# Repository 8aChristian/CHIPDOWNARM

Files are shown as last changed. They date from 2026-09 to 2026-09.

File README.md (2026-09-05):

# CHIPDOWNARM | Sub-GHz LoRaWAN & Industrial Telemetry Node

CHIPDOWNARM is a highly optimized, industrial-grade IoT telemetry edge node designed for mission-critical Sub-GHz LPWAN networks, remote monitoring, and smart agriculture deployments. Built around the high-performance **STMicroelectronics STM32WLE5** (ARM Cortex-M4 with integrated Sub-GHz LoRa/FSK transceiver), it delivers robust long-range communication with an ultra-low power footprint.

The board follows rigorous IPC (IPC-2152, IPC-2221) standards, featuring a wide-input high-efficiency switching power architecture (TPS62840), a highly stable 32MHz TCXO for RF precision, and an optimized 4-layer controlled-impedance stackup for impeccable RF Signal Integrity (SI) and Power Integrity (PI).

---

## 📸 Photorealistic 3D Renders

<p align="center">
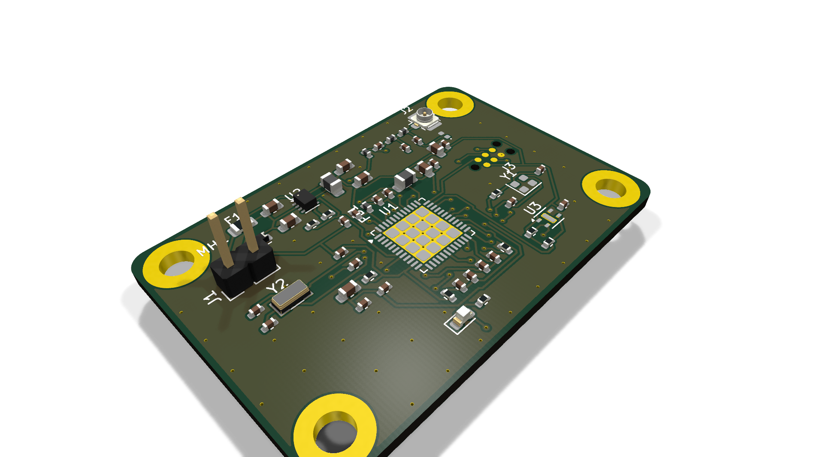
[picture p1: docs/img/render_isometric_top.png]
CHIPDOWNARM 3D Top View
  
</p>

<p align="center">
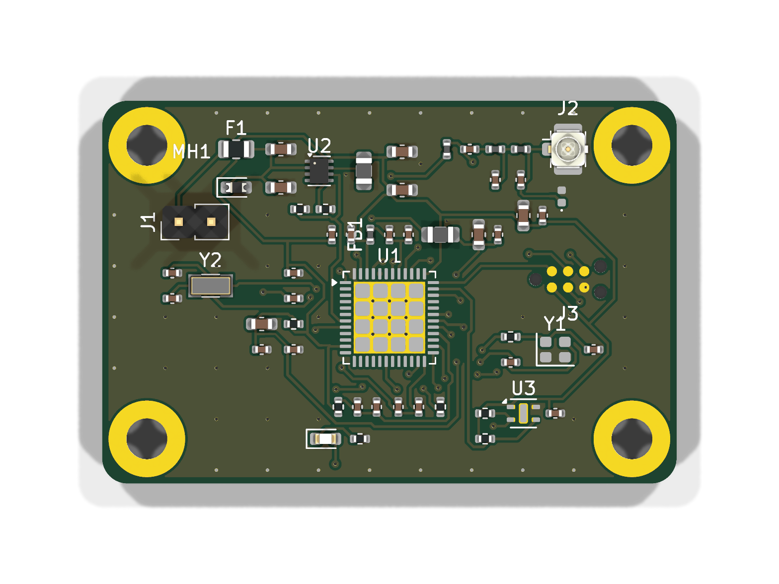
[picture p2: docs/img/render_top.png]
Top Orthographic View
  
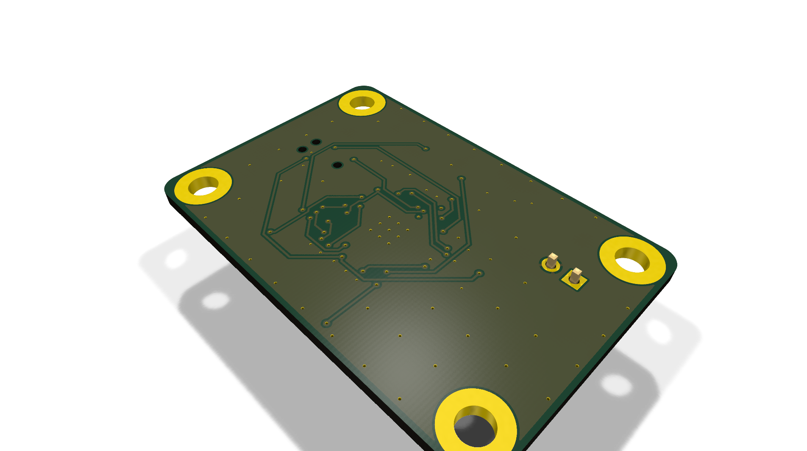
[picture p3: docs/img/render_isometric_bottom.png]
Bottom Isometric View
  
</p>

---

## 🏛️ System Architecture Diagram

```mermaid
flowchart TD
    subgraph PowerDomain["⚡ Power Architecture (1.8V - 6.5V)"]
        VIN["DC Power In (J1) / Li-SOCl2 / Li-Po"] --> F1["Polyfuse PTC (F1)"]
        F1 --> D1["TVS Diode Protection"]
        D1 --> U2["TI TPS62840 Buck (60nA Iq)"]
        U2 --> L1["1.5µH Shielded Inductor"]
        L1 --> VCC3["+3V0 System Rail"]
        VCC3 --> FB1["Ferrite Bead (FB1)"]
        FB1 --> VDDA["Filtered Analog Power (VDDA)"]
    end

    subgraph CoreDomain["🧠 Compute and RF Engine"]
        U1["STM32WLE5CCU6 (ARM Cortex-M4 @ 48MHz)"]
        Y1["32.000 MHz TCXO (Y1)"] -->|"RF Master Clock"| U1
        Y2["32.768 kHz RTC Crystal (Y2)"] -->|"Low Power RTC"| U1
        VCC3 --> U1
        VDDA --> U1
    end

    subgraph RFDomain["📡 Sub-GHz RF Frontend (150-960 MHz)"]
        U1 -->|"RF_PA_OUT"| RFFilt["LC Harmonics Filter & Matching Network"]
        RFFilt -->|"50Ω Coplanar Microstrip"| J2["SMA Edge-Mount Connector (J2)"]
    end

    subgraph SensorDomain["🌡️ Telemetry and Sensing"]
        U3["Sensirion SHTC3 (I2C)"] -->|"I2C1_SCL / I2C1_SDA"| U1
        VCC3 --> U3
    end

    subgraph DebugDomain["🔧 Diagnostics and Programming"]
        J3["Tag-Connect TC2030-IDC-NL"] -->|"SWDIO, SWCLK, NRST, SWO"| U1
    end

    classDef pwr fill:#f97316,stroke:#c2410c,stroke-width:2px,color:#fff;
    classDef core fill:#2563eb,stroke:#1d4ed8,stroke-width:2px,color:#fff;
    classDef rf fill:#16a34a,stroke:#15803d,stroke-width:2px,color:#fff;
    classDef sns fill:#9333ea,stroke:#7e22ce,stroke-width:2px,color:#fff;
    classDef dbg fill:#475569,stroke:#334155,stroke-width:2px,color:#fff;

    class PowerDomain,VIN,F1,D1,U2,L1,VCC3,FB1,VDDA pwr;
    class CoreDomain,U1,Y1,Y2 core;
    class RFDomain,RFFilt,J2 rf;
    class SensorDomain,U3 sns;
    class DebugDomain,J3 dbg;
```

---

## ⚡ Power Tree & Energy Profile

```mermaid
flowchart LR
    BATT["Battery / External Input<br/><b>1.8V - 6.5V</b>"] -->|F1: PTC Fuse| REG["TPS62840<br/><b>Buck Regulator</b><br/>Iq = 60 nA | Eff = 92%"]
    REG -->|VOUT = 3.0V| RAIL["+3V0 System Rail<br/>(Inner Layer 2 Plane)"]
    
    RAIL -->|"100nF + 4.7µF"| MCU["STM32WLE5 Core<br/>Sleep: 1.1 µA<br/>TX (+22dBm): 118 mA"]
    RAIL -->|"100nF"| SENS["SHTC3 Sensor<br/>Active: 800 µA<br/>Sleep: 0.2 µA"]
    RAIL -->|"100nF + TCXO Reg"| TCXO["32 MHz TCXO<br/>Warmup: 2 ms"]
    RAIL -->|FB1: Ferrite Filter| RF_ANA["RF & VDDA Power<br/>Multi-stage decoupling"]
```

---

## 🔬 PCB Layer Stackup & Controlled Impedance

The PCB is built on an industrial 4-Layer standard stackup (1.6mm nominal thickness, 1 oz / 35µm copper outer and inner layers) to guarantee excellent RF containment.

```text
========================================================================================
Layer 1 (Top / F.Cu): Component SMD Pads, 50Ω RF Coplanar Microstrips, Buck Power Loop
---------------------------------- Dielectric Prepreg (0.21mm, FR-4, Er=4.5) -----------
Layer 2 (Inner 1 / In1.Cu): Solid Continuous Ground Plane (GND) - Zero Slots
---------------------------------- Core Dielectric (1.065mm, FR-4, Er=4.5) -------------
Layer 3 (Inner 2 / In2.Cu): Dedicated +3V0 Power Plane & RF Return Shield
---------------------------------- Dielectric Prepreg (0.21mm, FR-4, Er=4.5) -----------
Layer 4 (Bottom / B.Cu): Digital Control Signals & Secondary Ground Shield
========================================================================================
```

### 🗺️ Individual Layer Vector Views

| Layer | Type | Function & High-Speed Details | Vector Preview |
| :--- | :--- | :--- | :--- |
| **L1 (F.Cu)** | Signal / RF | 50Ω Coplanar RF track, SMPS power loop, MCU breakouts | [View SVG](docs/img/layer_l1_top.svg) |
| **L2 (In1.Cu)** | Solid GND | 100% continuous reference ground, zero ground slots | [View SVG](docs/img/layer_l2_gnd.svg) |
| **L3 (In2.Cu)** | Power | Dedicated +3V0 power plane, ultra-low impedance distribution | [View SVG](docs/img/layer_l3_pwr.svg) |
| **L4 (B.Cu)** | Signal / Shield | I2C routing, debug traces, stitched ground plane | [View SVG](docs/img/layer_l4_bottom.svg) |

---

## ⚡ Technical Specifications

| Parameter | Specification | Engineering Details |
| :--- | :--- | :--- |
| **Input Supply Voltage** | **1.8V − 6.5V DC** | Polyfuse protection (F1) + Battery input conditioning for Li-Po/Li-SOCl2. |
| **Main Step-Down Converter** | **TI TPS62840 (1.8V-6.5V)** | Ultra-low $I_q$ (60 nA) high-efficiency buck regulator with compact shielded inductor. |
| **Main Processing Unit (MCU)** | **STM32WLE5CCU6** | ARM Cortex-M4 @ 48MHz, 256KB Flash, 64KB SRAM, integrated Sub-GHz Radio. |
| **Wireless Connectivity** | **LoRa / (G)FSK / (G)MSK** | Sub-GHz Radio (150 MHz to 960 MHz) compatible with LoRaWAN protocols. |
| **RF Clock Source** | **32.000 MHz TCXO** | High-stability Temperature Compensated Oscillator for precise RF modulation. |
| **Telemetry Sensor** | **Sensirion SHTC3** | Ultra-low power I2C Temperature and Humidity sensor (±2.0% RH, ±0.2°C). |
| **Debug Interface** | **SWD via Tag-Connect** | Zero-cost, zero-profile TC2030-IDC-NL footprint (No Legs) for SWD & SWO. |
| **RF Interface** | **SMA Edge-Mount** | 50Ω impedance-matched Coplanar Waveguide routing to SMA connector. |
| **Design Rule Check (DRC)** | **100% Passed (0 Errors)** | 0 Unrouted airwires, 0 clearance errors, full IPC-2221 compliance. |

---

## 📋 Comprehensive Bill of Materials (BOM)

| Item | Qty | Component / Value | Manufacturer | MPN | Description |
| :--- | :--- | :--- | :--- | :--- | :--- |
| **U1** | 1 | **STM32WLE5CCU6** | STMicroelectronics | STM32WLE5CCU6 | ARM Cortex-M4 Sub-GHz LoRa SoC (UFQFPN-48) |
| **U2** | 1 | **TPS62840DLCR** | Texas Instruments | TPS62840DLCR | Ultra-Low Iq Step-Down Converter |
| **U3** | 1 | **SHTC3** | Sensirion | SHTC3 | I2C Humidity and Temperature Sensor |
| **Y1** | 1 | **NT2016SA-32M** | NDK | NT2016SA-32M | 32.000MHz TCXO (Temperature Compensated) |
| **J1** | 1 | **SMA Edge-Mount** | Amphenol | 132136 | 50Ω SMA RF Connector |
| **J3** | 1 | **TC2030-IDC-NL** | Tag-Connect | TC2030-IDC-NL | 6-pin No-Legs SWD Programming Header |

*(For passive components, resistors, MLCCs, and exact footprints, please see [CHIPDOWNARM_BOM.xml](CHIPDOWNARM_BOM.xml))*

---

## 📁 Repository Structure

```text
CHIPDOWNARM/
├── CHIPDOWNARM.kicad_pcb        # KiCad 8/9 PCB Layout File (4-Layer, 0 DRC Errors)
├── CHIPDOWNARM.kicad_sch        # KiCad Schematic File
├── CHIPDOWNARM.kicad_pro        # KiCad Project Definitions
├── CHIPDOWNARM_Schematic.pdf    # Complete vector schematic PDF
├── CHIPDOWNARM.step             # High-precision 3D mechanical model (STEP AP214)
├── CHIPDOWNARM_BOM.xml          # Sourcing Bill of Materials
├── gerbers/                     # Standard RS-274X Fabrication Gerbers & Excellon Drills
│   ├── CHIPDOWNARM-F_Cu.gtl     # Top Copper Layer
│   ├── CHIPDOWNARM-In1_Cu.g1    # Layer 2 Ground Plane
│   ├── CHIPDOWNARM-In2_Cu.g2    # Layer 3 Power Plane
│   ├── CHIPDOWNARM-B_Cu.gbl     # Bottom Copper Layer
│   ├── CHIPDOWNARM.drl          # NC Drill file
│   └── ...                      # Masks, silkscreens, edge cuts
├── docs/
│   └── img/                     # 3D Photorealistic raytracing renders & SVG layer previews
│       ├── render_isometric_top.png
│       ├── render_isometric_bottom.png
│       ├── render_top.png
│       └── layer_l*.svg
├── .gitignore                   # Clean Git configuration for EDA projects
└── README.md                    # Comprehensive hardware documentation
```

---

## 🚀 How to Build & Open the Project

### Prerequisites
* EDA Suite: **[KiCad 8.0+](https://www.kicad.org/)** (Fully tested on KiCad 8 & 9).

### Opening in KiCad
1. Clone the repository:
   ```bash
   git clone https://github.com/8aChristian/CHIPDOWNARM.git
   cd CHIPDOWNARM
   ```
2. Open `CHIPDOWNARM.kicad_pro` inside KiCad.
3. Open the **Schematic Editor** to review the architecture.
4. Open the **PCB Editor** and hit `B` to recalculate all zone fills and inspect the perfectly clean 4-layer layout.
5. Press `Alt + 3` to open the interactive 3D viewer.

---

## 📜 License & Author

**Author**: Christian Ochoa ([@8aChristian](https://github.com/8aChristian))  
**Status**: Ready for Fabrication (0 Unrouted, 0 DRC Violations)  
**License**: Released under the MIT License.

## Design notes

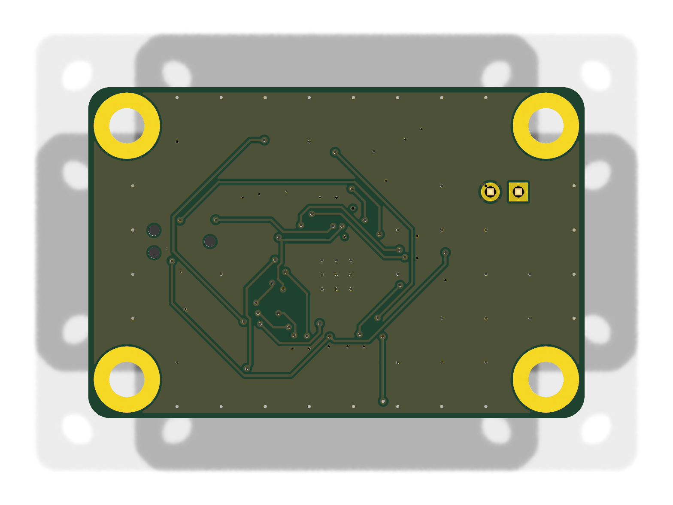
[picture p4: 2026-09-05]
docs/img/render_bottom.png

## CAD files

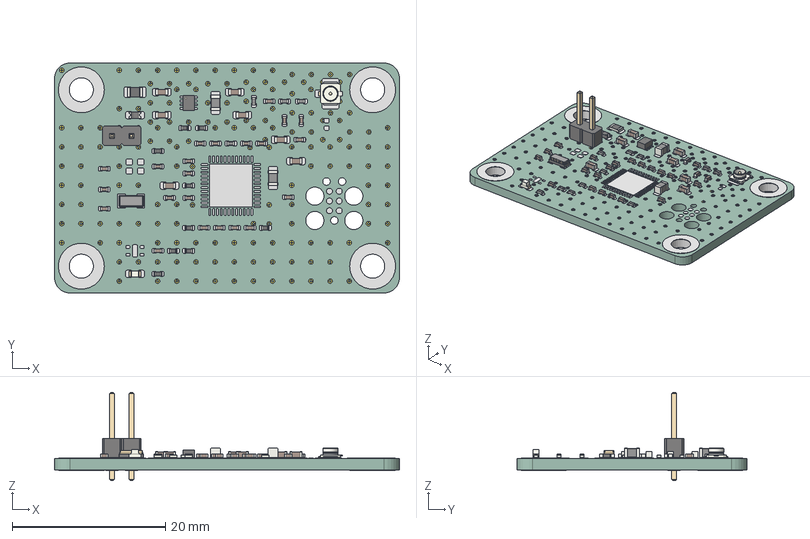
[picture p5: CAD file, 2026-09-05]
CHIPDOWNARM.step
45.0 x 30.0 x 11.5 mm
D_0603_1608Metric
C_0402_1005Metric x 22
Texas_VSON-HR-8_1.5x2mm_P0.5mm
C_0603_1608Metric x 7
L_0402_1005Metric x 4
R_0402_1005Metric x 9
Crystal_SMD_3215-2Pin_3.2x1.5mm
Fuse_0805_2012Metric
L_0805_2012Metric x 2
U.FL_Hirose_U.FL-R-SMT-1_Vertical
LED_0603_1608Metric
PinHeader_1x02_P2.54mm_Vertical
CHIPDOWNARM_copper
CHIPDOWNARM_pad
CHIPDOWNARM_via
CHIPDOWNARM_PCB

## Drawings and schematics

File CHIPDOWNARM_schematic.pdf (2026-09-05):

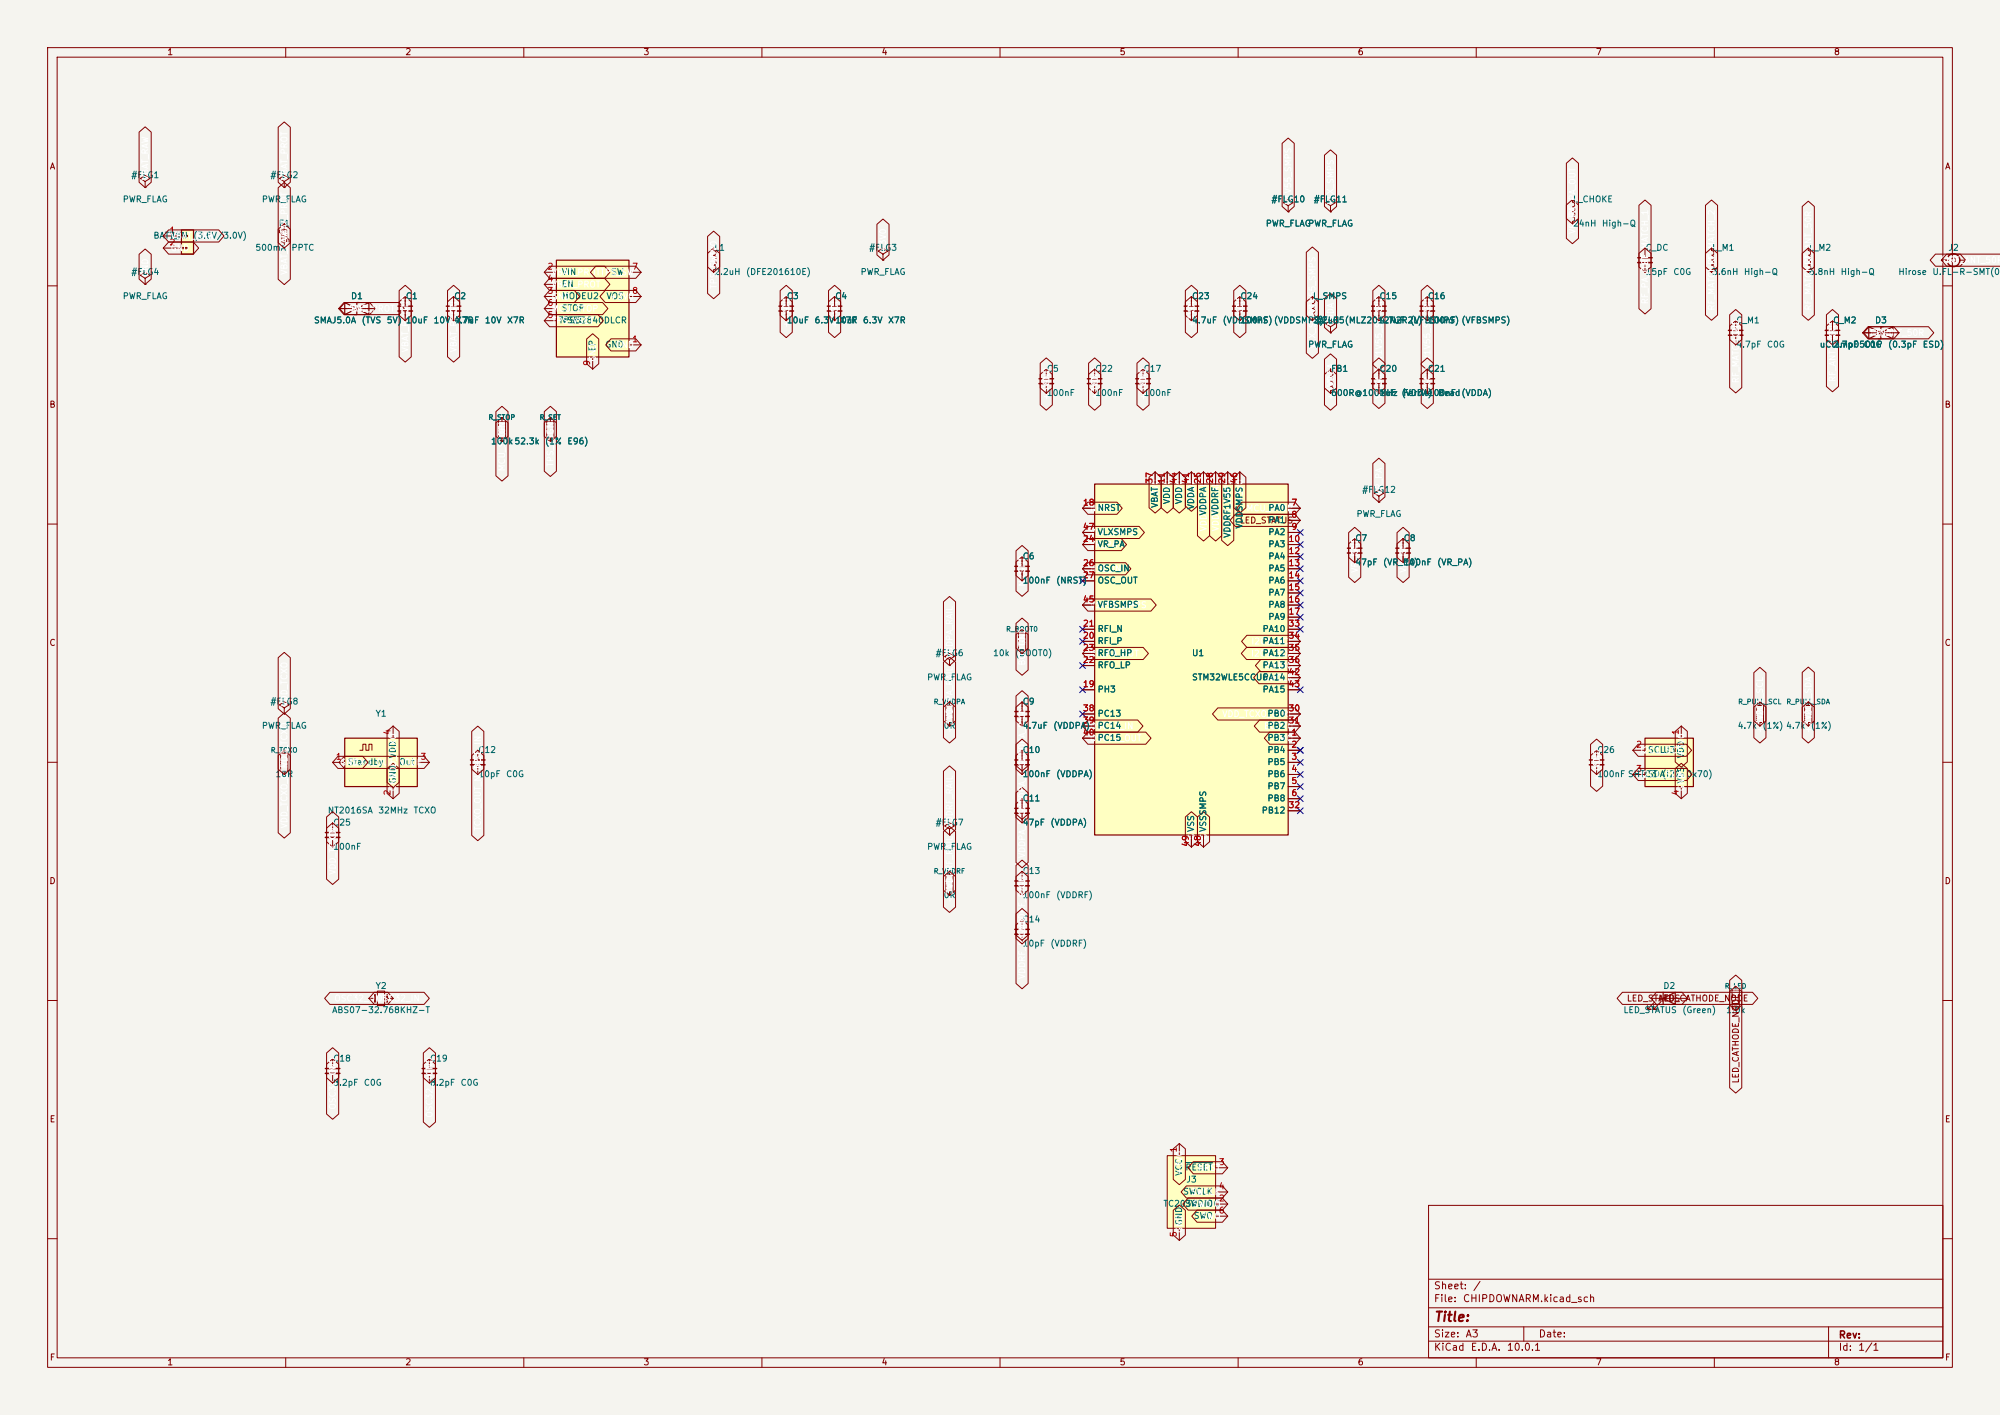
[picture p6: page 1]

Size: A3 | Rev: | F Date:
KiCad E.D.A. 10.0.1 | Id: 1/1

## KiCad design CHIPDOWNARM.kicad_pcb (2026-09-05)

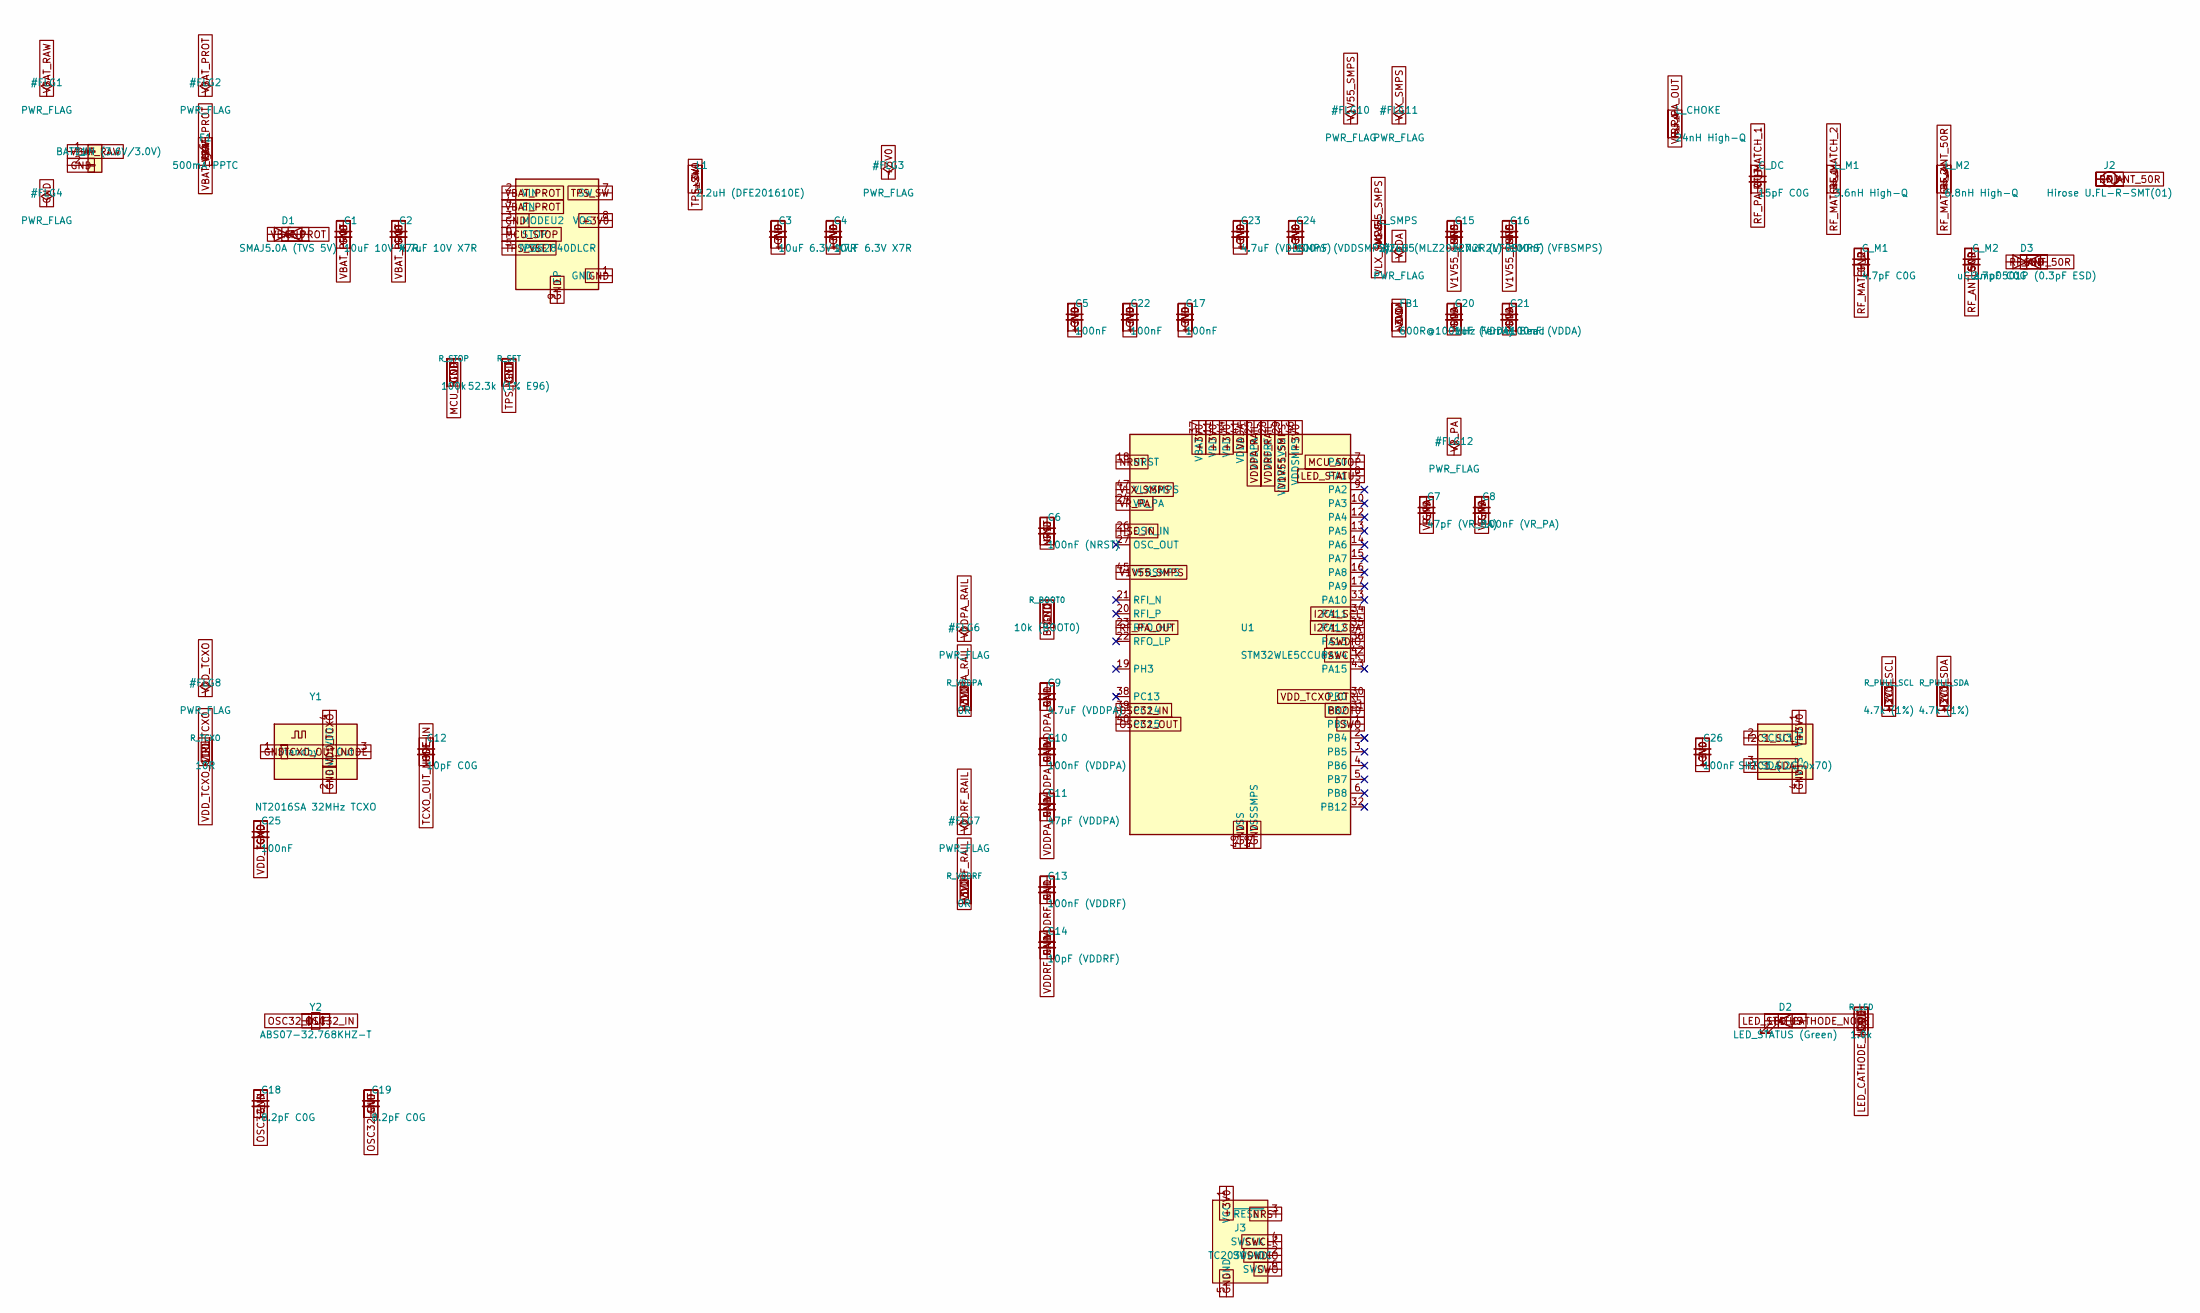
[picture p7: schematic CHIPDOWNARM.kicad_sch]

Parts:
C1: 10uF 10V X7R; C_0603_1608Metric
C2: 4.7uF 10V X7R; C_0603_1608Metric
C3, C4: 10uF 6.3V X7R; C_0603_1608Metric
C5, C17, C22, C25, C26: 100nF; C_0402_1005Metric
C6: 100nF (NRST); C_0402_1005Metric
C7: 47pF (VR_PA); C_0402_1005Metric
C8: 100nF (VR_PA); C_0402_1005Metric
C9: 4.7uF (VDDPA); C_0603_1608Metric
C10: 100nF (VDDPA); C_0402_1005Metric
C11: 47pF (VDDPA); C_0402_1005Metric
C12: 10pF C0G; C_0402_1005Metric
C13: 100nF (VDDRF); C_0402_1005Metric
C14: 10pF (VDDRF); C_0402_1005Metric
C15: 4.7uF (VFBSMPS); C_0603_1608Metric
C16: 100nF (VFBSMPS); C_0402_1005Metric
C18, C19: 8.2pF C0G; C_0402_1005Metric
C20: 1uF (VDDA); C_0402_1005Metric
C21: 100nF (VDDA); C_0402_1005Metric
C23: 4.7uF (VDDSMPS); C_0603_1608Metric
C24: 100nF (VDDSMPS); C_0402_1005Metric
C_DC: 15pF C0G; C_0402_1005Metric
C_M1: 4.7pF C0G; C_0402_1005Metric
C_M2: 2.7pF C0G; C_0402_1005Metric
D1: SMAJ5.0A (TVS 5V); D_0603_1608Metric
D2: LED_STATUS (Green); LED_0603_1608Metric
D3: uClamp0501P (0.3pF ESD); D_0402_1005Metric
F1: 500mA PPTC; Fuse_0805_2012Metric
FB1: 600R@100MHz Ferrite Bead; L_0402_1005Metric
J1: BATT_IN (3.6V/3.0V); PinHeader_1x02_P2.54mm_Vertical
J2: Hirose U.FL-R-SMT(01); U.FL_Hirose_U.FL-R-SMT-1_Vertical
J3: TC2030-IDC; Tag-Connect_TC2030-IDC-FP_2x03_P1.27mm_Vertical
L1: 2.2uH (DFE201610E); L_0805_2012Metric
L_CHOKE: 24nH High-Q; L_0402_1005Metric
L_M1: 3.6nH High-Q; L_0402_1005Metric
L_M2: 6.8nH High-Q; L_0402_1005Metric
L_SMPS: 2.2uH (MLZ2012N2R2L); L_0805_2012Metric
R_BOOT0: 10k (BOOT0); R_0402_1005Metric
R_LED: 1.0k; R_0402_1005Metric
R_PULL_SCL: 4.7k (1%); R_0402_1005Metric
R_PULL_SDA: 4.7k (1%); R_0402_1005Metric
R_SET: 52.3k (1% E96); R_0402_1005Metric
R_STOP: 100k; R_0402_1005Metric
R_TCXO: 10R; R_0402_1005Metric
R_VDDPA: 0R; R_0402_1005Metric
R_VDDRF: 0R; R_0402_1005Metric
U1: STM32WLE5CCU6; QFN-48-1EP_7x7mm_P0.5mm_EP5.6x5.6mm
U2: TPS62840DLCR; Texas_VSON-HR-8_1.5x2mm_P0.5mm
U3: SHTC3 (I2C 0x70); Sensirion_DFN-4-1EP_2x2mm_P1mm_EP0.7x1.6mm
Y1: NT2016SA 32MHz TCXO; Oscillator_SMD_SiT_PQFN-4Pin_2.0x1.6mm
Y2: ABS07-32.768KHZ-T; Crystal_SMD_3215-2Pin_3.2x1.5mm

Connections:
+3V0: C3.1, C4.1, C5.1, C17.1, C22.1, C23.1, C24.1, C26.1, FB1.1, J3.1 (VCC), L1.2, R_PULL_SCL.1, R_PULL_SDA.1, R_VDDPA.1, R_VDDRF.1, U1.11 (VDD), U1.37 (VBAT), U1.44 (VDD), U1.46 (VDDSMPS), U2.8 (VOS), U3.1 (VDD)
BOOT0: R_BOOT0.1, U1.31 (PB2)
GND: C1.2, C2.2, C3.2, C4.2, C5.2, C6.2, C7.2, C8.2, C9.2, C10.2, C11.2, C13.2, C14.2, C15.2, C16.2, C17.2, C18.2, C19.2, C20.2, C21.2, C22.2, C23.2, C24.2, C25.2, C26.2, C_M1.2, C_M2.2, D1.2 (A2), D3.2 (A2), J1.2, J2.2 (Ext), J3.5 (GND), R_BOOT0.2, R_LED.2, R_SET.2, R_STOP.2, U1.48 (VSSSMPS), U1.49 (VSS), U2.1 (GND), U2.3 (MODE), U2.9 (EP), U3.4 (VSS), Y1.1 (Standby), Y1.2 (GND)
HSE_IN: C12.2, U1.26 (OSC_IN)
I2C1_SCL: R_PULL_SCL.2, U1.34 (PA11), U3.2 (SCL)
I2C1_SDA: R_PULL_SDA.2, U1.35 (PA12), U3.3 (SDA)
LED_CATHODE_NODE: D2.1 (K), R_LED.1
LED_STATUS: D2.2 (A), U1.8 (PA1)
MCU_STOP: R_STOP.1, U1.7 (PA0), U2.6 (STOP)
NRST: C6.1, J3.3 (~RESET), U1.18 (NRST)
OSC32_IN: C18.1, U1.39 (PC14), Y2.1
OSC32_OUT: C19.1, U1.40 (PC15), Y2.2
RF_ANT_50R: C_M2.1, D3.1 (A1), J2.1 (In), L_M2.2
RF_MATCH_1: C_DC.2, L_M1.1
RF_MATCH_2: C_M1.1, L_M1.2, L_M2.1
RF_PA_OUT: C_DC.1, L_CHOKE.2, U1.23 (RFO_HP)
SWCLK: J3.4 (SWCLK), U1.42 (PA14)
SWDIO: J3.2 (SWDIO), U1.36 (PA13)
SWO: J3.6 (SWO), U1.1 (PB3)
TCXO_OUT_NODE: C12.1, Y1.3 (Out)
TPS_SW: L1.1, U2.7 (SW)
TPS_VSET: R_SET.1, U2.5 (VSET)
V1V55_SMPS: C15.1, C16.1, L_SMPS.2, U1.29 (VDDRF1V55), U1.45 (VFBSMPS)
VBAT_PROT: C1.1, C2.1, D1.1 (A1), F1.2, U2.2 (VIN), U2.4 (EN)
VBAT_RAW: F1.1, J1.1
VDDA: C20.1, C21.1, FB1.2, U1.41 (VDDA)
VDDPA_RAIL: C9.1, C10.1, C11.1, R_VDDPA.2, U1.25 (VDDPA)
VDDRF_RAIL: C13.1, C14.1, R_VDDRF.2, U1.28 (VDDRF)
VDD_TCXO: C25.1, R_TCXO.2, Y1.4 (VDD)
VDD_TCXO_CTRL: R_TCXO.1, U1.30 (PB0)
VLX_SMPS: L_SMPS.1, U1.47 (VLXSMPS)
VR_PA: C7.1, C8.1, L_CHOKE.1, U1.24 (VR_PA)

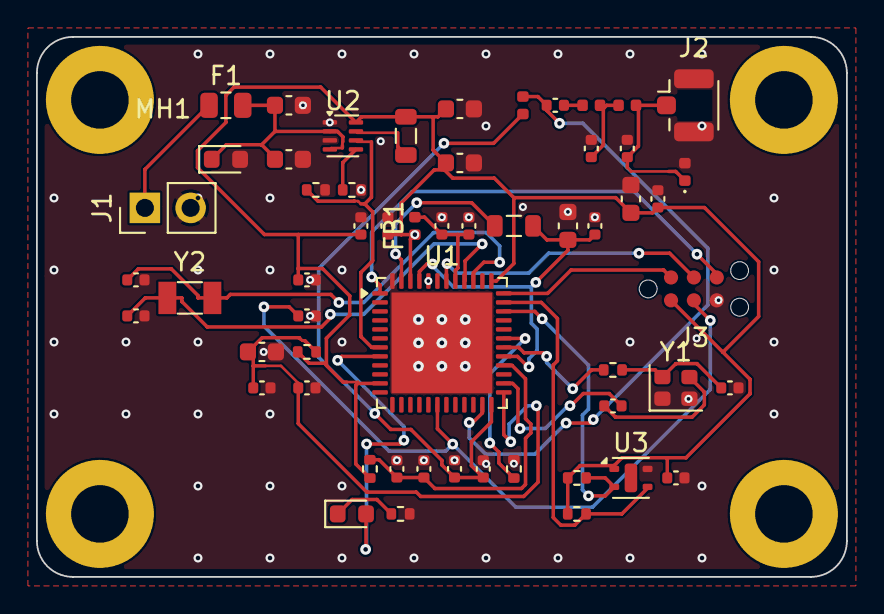
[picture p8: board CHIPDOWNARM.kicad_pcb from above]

Board: 4 copper layers, 45.0 x 30.0 mm, 60 parts (0 on the bottom side), 32 nets.

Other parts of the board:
MH1, MH2, MH3, MH4: MountingHole_3.2mm_M3_Pad_Via
